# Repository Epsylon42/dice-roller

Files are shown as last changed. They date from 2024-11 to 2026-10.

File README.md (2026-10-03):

# Dice-Roller

Electronic dice roller for all the dice rolling needs. Includes d4, d6, d8, d10, d12 and d20.

Partially implemented:
* Battery display (currently shows raw analog pin input, without converting it to voltage or %)
* d100 / percentile dice (can be done by holding down d10 button, but is has not been finished and currently does not work correctly)

This repository contains two PCB versions - v1 and v2.
* v1 has been built and tested, but the kicad files have been lost. The recovered gerbers are in `dice-roller-pcb/v1-gerbers`.
* v2 is in the actual kicad project. It is meant to support battery charging status and persistent settings, but most of it is not implemented.

The firmware supports either version, selected via platformio environments

## Building firmware

* Install platformio
* Download dependencies: `git submodule update --init`
* Apply `firmware/lib/Adafruit-GFX-Library.patch` to `firmware/lib/Adafruit-GFX-Library`
  * The OLED display is installed upside-down on the PCB, and this patch includes a horrible hack to flip the text.
* Build firmware using platformio: `pio run -e v1` or `pio run -e v2`, depending on the target pcb version

Firmware is flashed via the UART header. To enable esp8266 flashing mode - hold the 0 button when booting

## Pictures

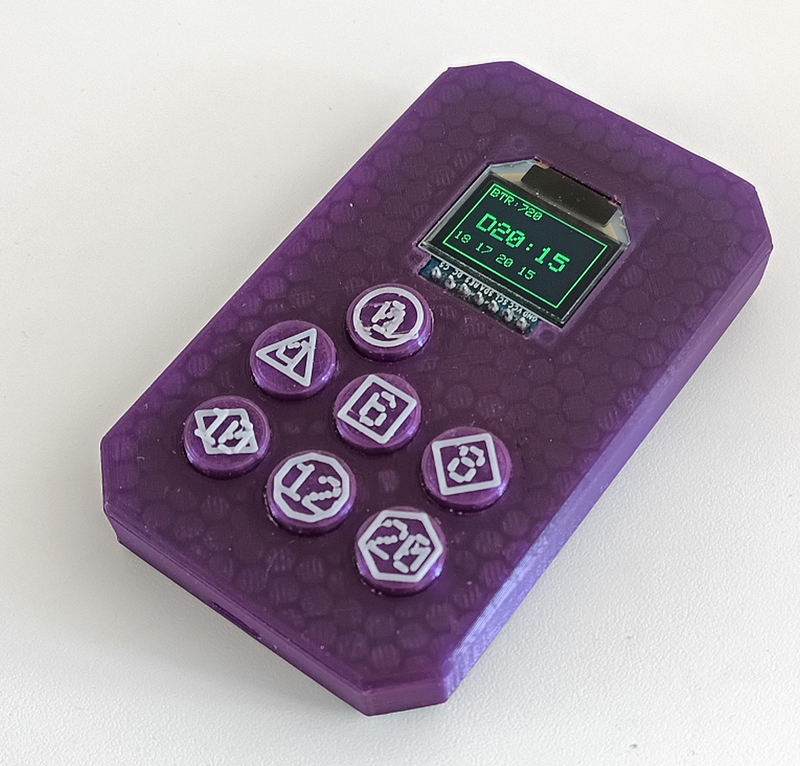
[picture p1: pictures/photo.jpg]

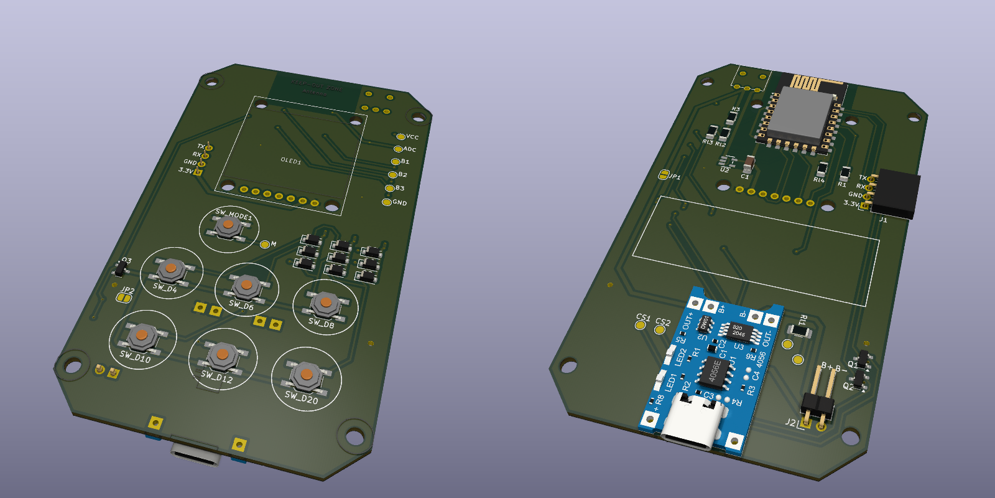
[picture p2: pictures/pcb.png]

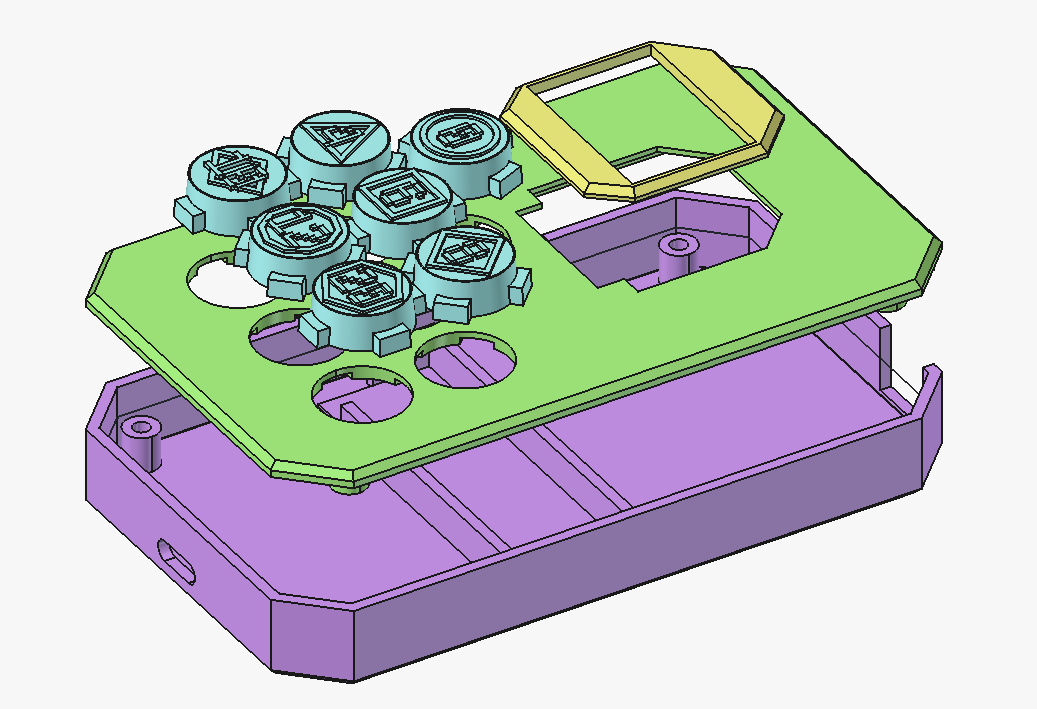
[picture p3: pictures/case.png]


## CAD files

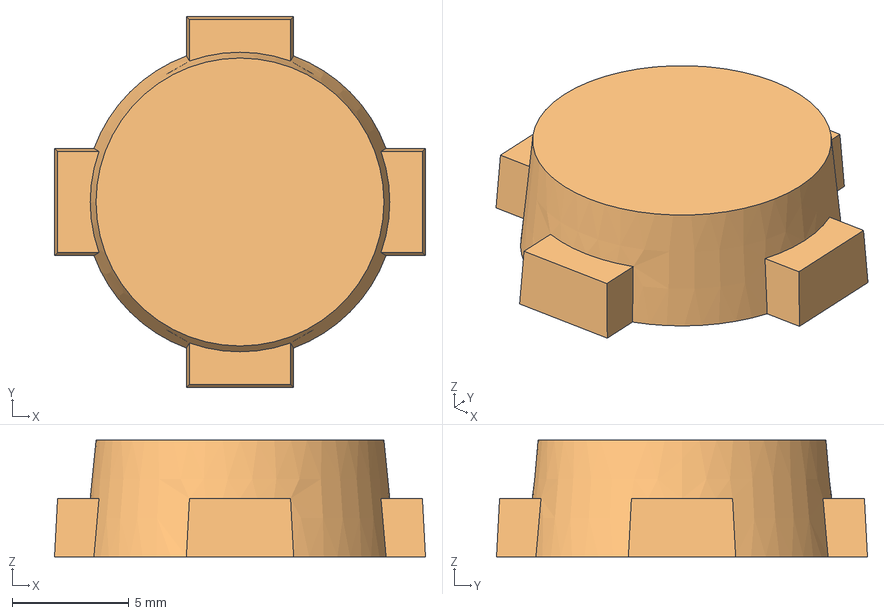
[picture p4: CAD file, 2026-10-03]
case/Button.FCStd
15.9 x 15.9 x 5.00 mm
ButtonBody
ButtonCutout

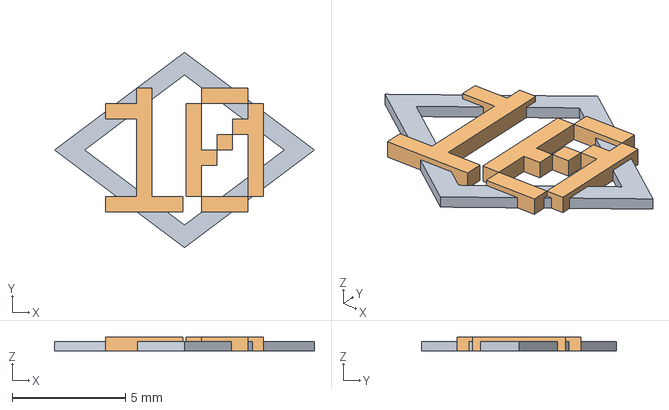
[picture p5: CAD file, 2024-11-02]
case/ButtonText.FCStd
11.5 x 8.64 x 0.6 mm
Text003

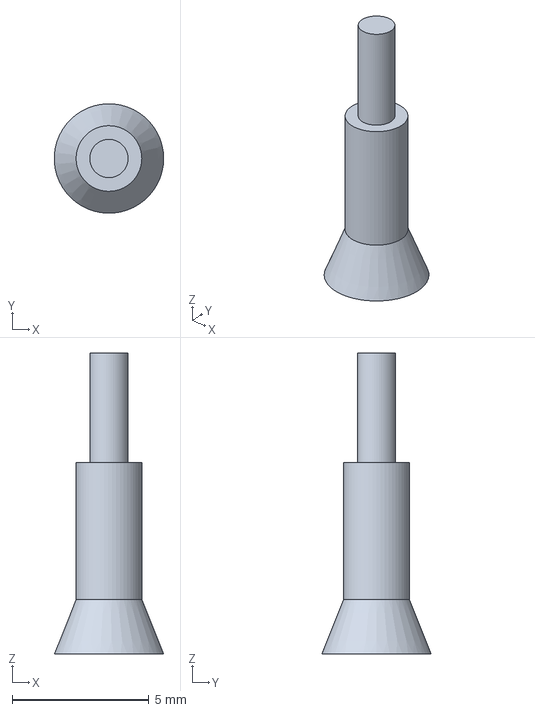
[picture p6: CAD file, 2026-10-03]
case/ScrewCutout.FCStd
4.00 x 4.00 x 11.0 mm

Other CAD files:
case/Parameters.FCStd

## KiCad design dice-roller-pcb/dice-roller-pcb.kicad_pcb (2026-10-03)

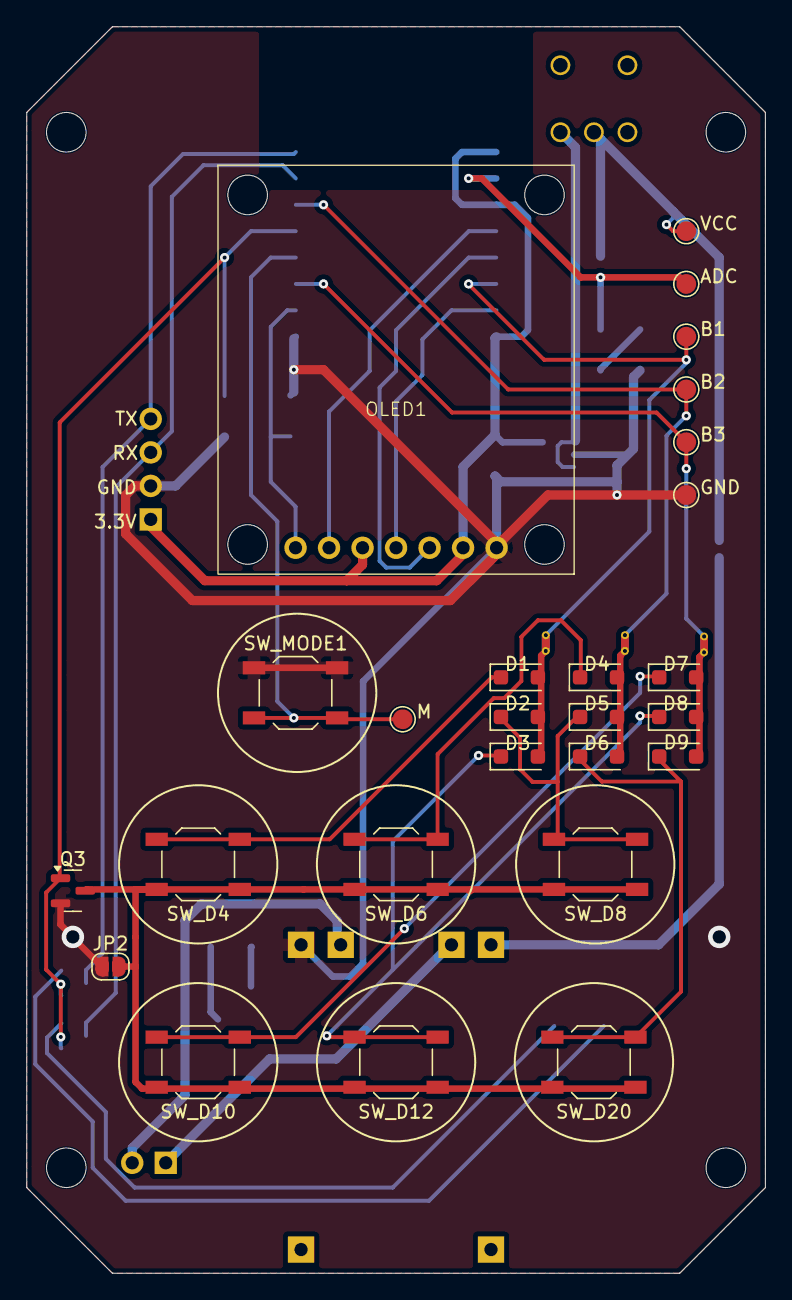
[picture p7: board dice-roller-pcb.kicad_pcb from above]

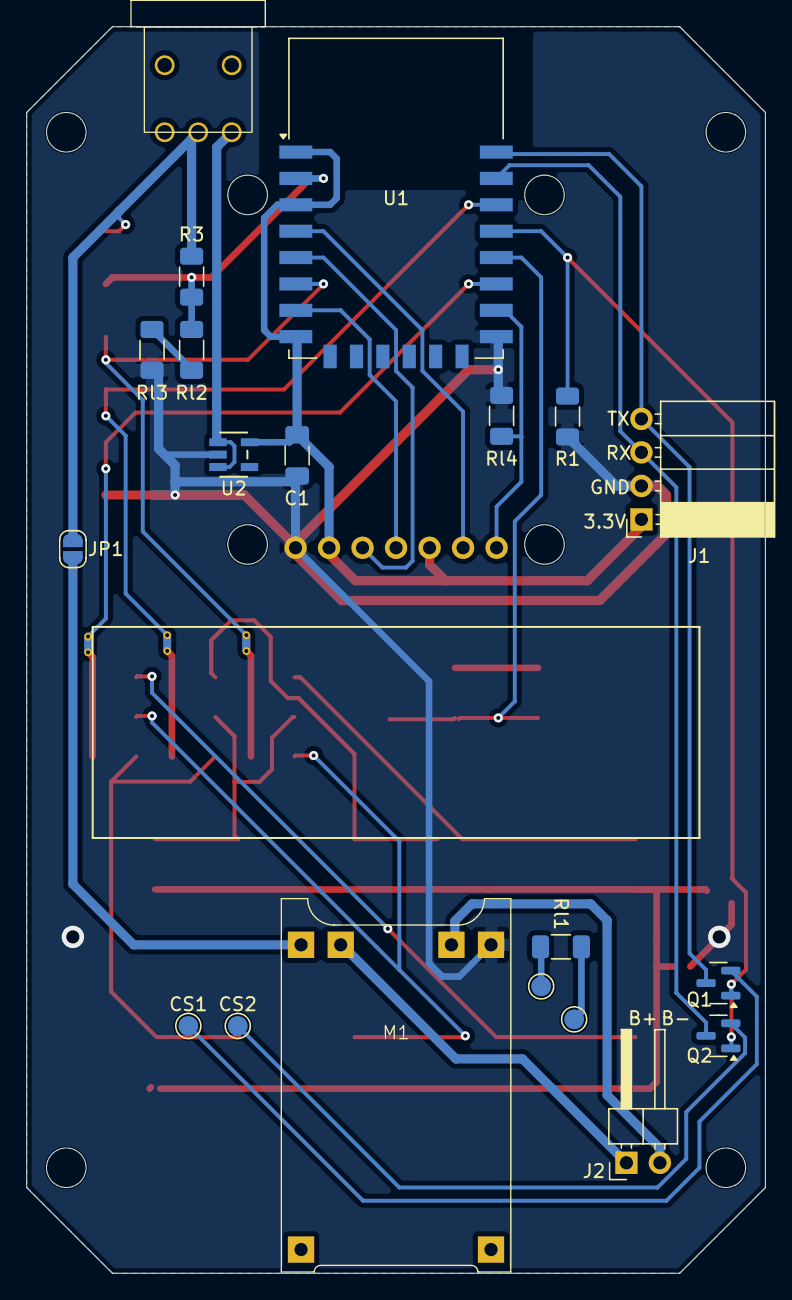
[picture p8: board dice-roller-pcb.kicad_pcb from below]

Board: 2 copper layers, 56.0 x 94.5 mm, 47 parts (18 on the bottom side), 32 nets.

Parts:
C1: 10uF; C_1206_3216Metric_Pad1.33x1.80mm_HandSolder
CS1, CS2: TestPoint; TestPoint_Pad_D1.5mm
D1, D2, D3, D4, D5, D6, D7, D8, D9: 1N4148W; D_SOD-123F
J1: Conn_01x04_Pin; PinSocket_1x04_P2.54mm_Horizontal
J2: Conn_01x02_Socket; PinHeader_1x02_P2.54mm_Horizontal
JP1, JP2: SolderJumper_2_Open; SolderJumper-2_P1.3mm_Open_RoundedPad1.0x1.5mm
M1: TP4056-USBC
NT14, NT15, NT16: NetTie_2; NetTie-2_THT_Pad0.3mm
OLED1: OLED
Q1, Q2, Q3: AO3400; SOT-23
R1, R3: 100K; R_1206_3216Metric_Pad1.30x1.75mm_HandSolder
Rl1, Rl2, Rl3, Rl4: 10K; R_1206_3216Metric_Pad1.30x1.75mm_HandSolder
SW_D4, SW_D6, SW_D8, SW_D10, SW_D12, SW_D20: SW_Push; SW_SPST_TL3342
SW_MODE1: SW_Push; SW_SPST_TL3342
SW_POWER1: SW_DPDT_x2; SW
TP1, TP2, TP3, TP4, TP5, TP6, TP8: TestPoint; TestPoint_Pad_D1.5mm
U1: ESP-12F; ESP-12E
U2: RT9013-33GB; SOT-23-5_RIT

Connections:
+3.3V: C1.2, J1.1, OLED1.2 (VCC), OLED1.5 (RES), U1.1 (~RST), U1.3 (EN), U1.8 (VCC), U2.5 (VOUT)
/ADC: R3.2, Rl2.2, TP5.1 (1_1), U1.2 (ADC)
/B1: NT14.1, TP3.1 (1_1), U1.6 (GPIO12)
/B1_BUS: D1.2 (A), D2.2 (A), D3.2 (A), NT14.2
/B2: NT15.1, TP2.1 (1_1), U1.20 (GPIO5)
/B2_BUS: D4.2 (A), D5.2 (A), D6.2 (A), NT15.2
/B3: NT16.1, TP1.1 (1_1), U1.17 (GPIO2)
/B3_BUS: D7.2 (A), D8.2 (A), D9.2 (A), NT16.2
/B+: J2.1, M1.3 (B+)
/B-: J2.2, M1.4 (B-)
/CHIP_RX: J1.3, Q2.3 (D), U1.21 (GPIO3/RXD)
/CHIP_TX: J1.4, Q1.3 (D), U1.22 (GPIO1/TXD)
/COPI: OLED1.4 (SDA), U1.7 (GPIO13)
/CS: OLED1.7 (SC), Rl4.2, U1.16 (GPIO15)
/CS1: CS1.1 (1_1), Q1.2 (S)
/CS2: CS2.1 (1_1), Q2.2 (S)
/MODE_SW: SW_MODE1.2, TP8.1 (1_1), U1.18 (GPIO0)
/OLED_DC: OLED1.6 (DC), U1.4 (GPIO16)
/PERIPHERAL_EN: Q1.1 (G), Q2.1 (G), Q3.1 (G), R1.1, U1.19 (GPIO4)
/SCLK: OLED1.3 (SCL), U1.5 (GPIO14)
GND: C1.1, J1.2, JP2.1 (A), M1.6 (OUT-), OLED1.1 (GND), Q3.2 (S), R1.2, Rl3.1, Rl4.1, SW_MODE1.1, TP4.1 (1_1), U1.15 (GND), U2.2 (GND)
unnamed: D1.1 (K), SW_D4.2
unnamed: D2.1 (K), D5.1 (K), SW_D8.2
unnamed: D3.1 (K), D8.1 (K), SW_D12.2
unnamed: D4.1 (K), SW_D6.2
unnamed: D6.1 (K), D9.1 (K), SW_D20.2
unnamed: D7.1 (K), SW_D10.2
unnamed: JP1.1 (A), M1.5 (OUT+)
unnamed: JP2.2 (B), Q3.3 (D), SW_D4.1, SW_D6.1, SW_D8.1, SW_D10.1, SW_D12.1, SW_D20.1
unnamed: Rl2.1, Rl3.2
unnamed: SW_POWER1.3 (C), U2.1 (VIN), U2.3 (EN)
VCC: JP1.2 (B), R3.1, SW_POWER1.2 (B), TP6.1 (1_1)

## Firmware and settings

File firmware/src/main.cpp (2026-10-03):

#include <array>
#include <cinttypes>
#include <chrono>

#include <Arduino.h>
#include <SPI.h>
#include <ESP8266WiFi.h>

#include "constants.h"
#include "dice.h"
#include "display.h"
#include "sleep_utils.h"
//#include "settings.h"
#include "ButtonEncoder.h"

using namespace std::chrono;

#if 1 == HARDWARE_VERSION
Adafruit_SSD1331 g_display_device = Adafruit_SSD1331(&SPI, PIN_CS, PIN_DC, PIN_RST);
#elif 2 == HARDWARE_VERSION
Adafruit_SSD1331 g_display_device = Adafruit_SSD1331(&SPI, PIN_CS, PIN_DC);
#endif

ButtonEncoder<3> g_dice_buttons{{PIN_B1, PIN_B2, PIN_B3}};
ButtonEncoder<1> g_mode_button{{PIN_MODE_SW}};

//SettingsStorage g_settings_storage;
//Settings g_settings{g_settings_storage.settings};

ESP8266TrueRandomClass g_rng{};

#define	BLACK           0x0000
#define	BLUE            0x001F
#define	RED             0xF800
#define	GREEN           0x07E0
#define CYAN            0x07FF
#define MAGENTA         0xF81F
#define YELLOW          0xFFE0
#define WHITE           0xFFFF

uint16_t const COLOR = GREEN;

void setup() {
    Serial.begin(115200);
    Serial.print("Serial ON");

    disable_modem();

    Serial.print("Setup done");
    g_display_device.begin();
    Serial.print("Display initialized");
    g_display_device.fillScreen(BLACK);

    g_display_device.drawRect(0, 0, g_display_device.width(), g_display_device.height(), COLOR);
    g_display_device.setCursor(0,0);
    g_display_device.setTextColor(COLOR);
}


void callback() {
    Serial.print("End LightSleep:");
    Serial.println(millis());
    Serial.flush();
}

void goToSleep() {
    uint32_t sleep_time_in_ms = 2000;
    Serial.print("go to LightSleep:");
    Serial.println(millis());
    Serial.flush();

    wifi_set_opmode(NULL_MODE);
    wifi_fpm_set_sleep_type(LIGHT_SLEEP_T);
    wifi_fpm_set_wakeup_cb(callback);
    gpio_pin_wakeup_enable(GPIO_ID_PIN(PIN_MODE_SW), GPIO_PIN_INTR_LOLEVEL);
    gpio_pin_wakeup_enable(GPIO_ID_PIN(PIN_B1), GPIO_PIN_INTR_LOLEVEL);
    gpio_pin_wakeup_enable(GPIO_ID_PIN(PIN_B2), GPIO_PIN_INTR_LOLEVEL);
    gpio_pin_wakeup_enable(GPIO_ID_PIN(PIN_B3), GPIO_PIN_INTR_LOLEVEL);
    wifi_fpm_open();
    wifi_fpm_do_sleep(0xFFFFFFF);
    delay(100);
    Serial.println("Woke up");
}

enum class CheckRollsResult {
    Processing,
    Idle,
};
CheckRollsResult check_rolls();

void loop() {
    if (check_rolls() == CheckRollsResult::Idle) {
        delay(50);
        goToSleep();
    }
}

bool full_cleared = true;
void clearScreen() {
    g_display_device.fillRect(1, 1, g_display_device.width() - 2, g_display_device.height() - 2, BLACK);
    if (full_cleared) {
        g_display_device.drawRect(0, 0, g_display_device.width(), g_display_device.height(), COLOR);
        full_cleared = false;
    }
}

DiceDescription const* history_dice = nullptr;
std::array<uint16_t, 6> roll_history;
size_t roll_history_size;
bool history_redraw_required = false;

void updHistory(DiceDescription const* dice, uint16_t value)
{
    if (dice != history_dice) {
        history_dice = dice;
        roll_history_size = 0;
    }

    if (roll_history_size >= roll_history.size()) {
        for (size_t i = 0; i < roll_history.size() - 1; i += 1) {
            roll_history[i] = roll_history[i + 1];
        }
        roll_history_size -= 1;
    }

    roll_history[roll_history_size] = value;
    roll_history_size += 1;
    history_redraw_required = true;
}

void clearHistory() {
    history_dice = nullptr;
    roll_history_size = 0;
}

void flushHistory() {
    if (history_redraw_required) {
        history_redraw_required = false;
        g_display_device.setTextSize(1);
        g_display_device.setCursor(g_display_device.width() - 10, 7);

        for (size_t i = 0; i < roll_history_size; i += 1) {
            g_display_device.print(roll_history[i]);
            g_display_device.print(" ");
        }

        // display battery. should be moved elsewhere
        uint16_t battery_reading = analogRead(A0);
        g_display_device.setCursor(g_display_device.width() - 10, g_display_device.height() - 12);
        g_display_device.print("BTR:");
        g_display_device.print(battery_reading);
    }

}

CheckRollsResult check_rolls() {
    auto const c_d100_delay = 2s;

    auto const held_for = g_dice_buttons.since_last_update();

    g_mode_button.update();
    if (g_mode_button.is_just_pressed(1)) {
        clearScreen();
        clearHistory();
    } else if (g_mode_button.is_pressed(1) && g_mode_button.just_held_for(1s)) {
        g_display_device.fillScreen(BLACK);
        full_cleared = true;
    }

    g_display_device.setTextSize(2);
    g_dice_buttons.update();
    for (auto const& dice : DICE_DESCRIPTION) {
        if (g_dice_buttons.is_just_pressed(dice.button)) {
            clearScreen();
            g_display_device.setCursor(g_display_device.width() - 1 - 12 * 2, g_display_device.height() / 2 - 11);
            g_display_device.print(dice.name.data());
            return CheckRollsResult::Processing;
        } else if (dice.size == 10 && g_dice_buttons.is_pressed(dice.button) && g_dice_buttons.just_held_for(c_d100_delay)) {
            clearScreen();
            g_display_device.setCursor(g_display_device.width() - 1 - 12 * 2, g_display_device.height() / 2 - 11);
            g_display_device.print(DICE_D100.name.data());
            return CheckRollsResult::Processing;
        } else if (g_dice_buttons.is_just_released(dice.button)) {
            uint32_t value;
            bool const is_d100 = dice.size == 10 && held_for >= c_d100_delay;
            value = is_d100 ? DICE_D100.roll() : dice.roll();
            updHistory(is_d100 ? &DICE_D100 : &dice, value);
            std::array<char, 32> value_buf;
            snprintf(value_buf.data(), value_buf.size(), "%" PRIu32, value);

            g_display_device.print(":");
            if (value < 10) {
                g_display_device.print(" ");
            }
            g_display_device.print(value_buf.data());
        }
    }

    flushHistory();

    if (g_dice_buttons.is_released() && g_mode_button.is_released()) {
        return CheckRollsResult::Idle;
    } else {
        return CheckRollsResult::Processing;
    }
}

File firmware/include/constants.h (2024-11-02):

#pragma once

#include <array>
#include <cstdint>
#include <cstdlib>

constexpr uint8_t PIN_CS   = 15;
constexpr uint8_t PIN_DC   = 16;

#if 1 == HARDWARE_VERSION
    constexpr uint8_t PIN_B1      = 5;
    constexpr uint8_t PIN_B2      = 4;
    constexpr uint8_t PIN_B3      = 2;
    constexpr uint8_t PIN_RST = 12;
#elif 2 == HARDWARE_VERSION
    constexpr uint8_t PIN_B1      = 12;
    constexpr uint8_t PIN_B2      = 5;
    constexpr uint8_t PIN_B3      = 2;
    constexpr uint8_t PIN_PERIPHERAL_EN = 5;
#else
#    ifdef HARDWARE_VERSION
#        error Unsupported HARDWARE_VERSION value
#    else
#        error HARDWARE_VERSION must be defined
#    endif
#endif

constexpr uint8_t PIN_MODE_SW = 0;
constexpr uint8_t PIN_CS1     = 1;
constexpr uint8_t PIN_CS2     = 3;

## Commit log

2024-11-02 Import project
    [Button.FCStd, ButtonText.FCStd, Parameters.FCStd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]
2026-10-03 Update repository
    [Button.FCStd, ScrewCutout.FCStd, case.FCStd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]
